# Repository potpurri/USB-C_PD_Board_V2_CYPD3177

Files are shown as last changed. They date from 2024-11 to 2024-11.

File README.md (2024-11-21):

# USB Type-C PD Voltage and Current Selection PCB

This PCB is designed to provide selectable output voltages and currents using the Infineon CYPD3177 USB Type-C port controller. It's equipped with switches that allow you to set the output voltage to 5V, 9V, 12V, 15V, or 20V and the current to 1A, 2A, 3A, 4A, or 5A.

## Features

- **USB Type-C Controller**: CYPD3177 with integrated fault protection and wide operating temperature range.
- **Selectable Output Voltage**: 5V, 9V, 12V, 15V, or 20V.
- **Selectable Output Current**: 1A, 2A, 3A, 4A, or 5A.
- **Compact Design**: Suitable for a variety of applications, including power tools, wearables, IoT devices, and more.
- **Turn ON Switch**: Switch to turn ON/OFF module.

## Voltage and Current Settings

The output voltage and current can be adjusted using switches on the PCB. SW1 is a SP4T switch and SW2 is a SPST switch. To use SW1, SW2 must be in position 1.  Refer to the table below for the settings:

| Voltage Setting | Output Voltage |
|---|---|
| SW1-1 | 5V |
| SW1-2 | 9V |
| SW1-3 | 12V |
| SW1-4 | 15V |
| SW2-2 | 20V |

| Current Setting | Output Current |
|---|---|
| SW1-1 | 1A |
| SW1-2 | 2A |
| SW1-3 | 3A |
| SW1-4 | 4A |
| SW2-2 | 5A |

## Images

### Schematic
Schematic

### 3D Renderings
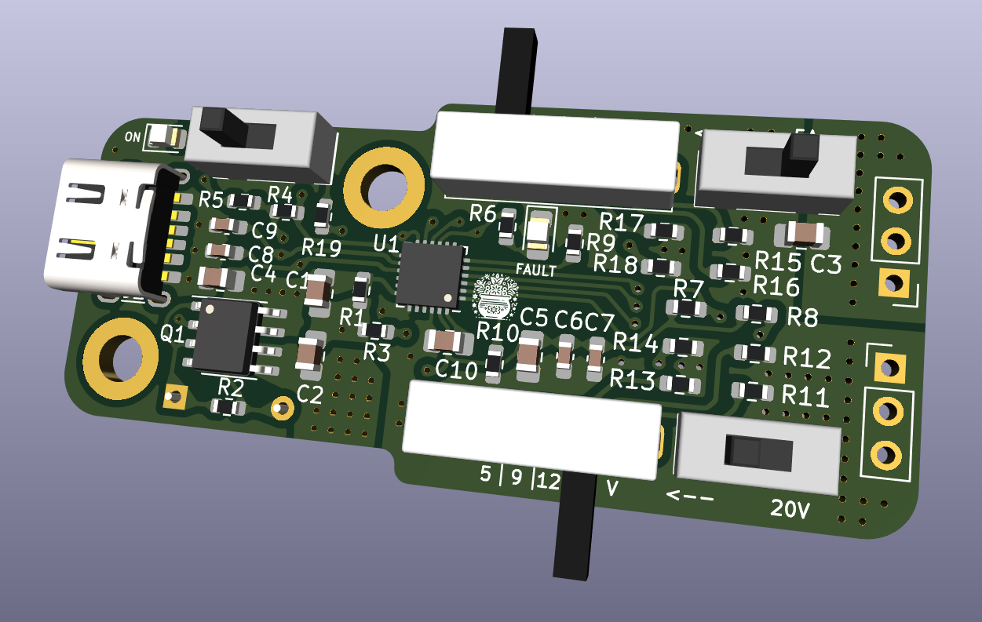
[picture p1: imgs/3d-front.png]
3D Front
- Front View: 
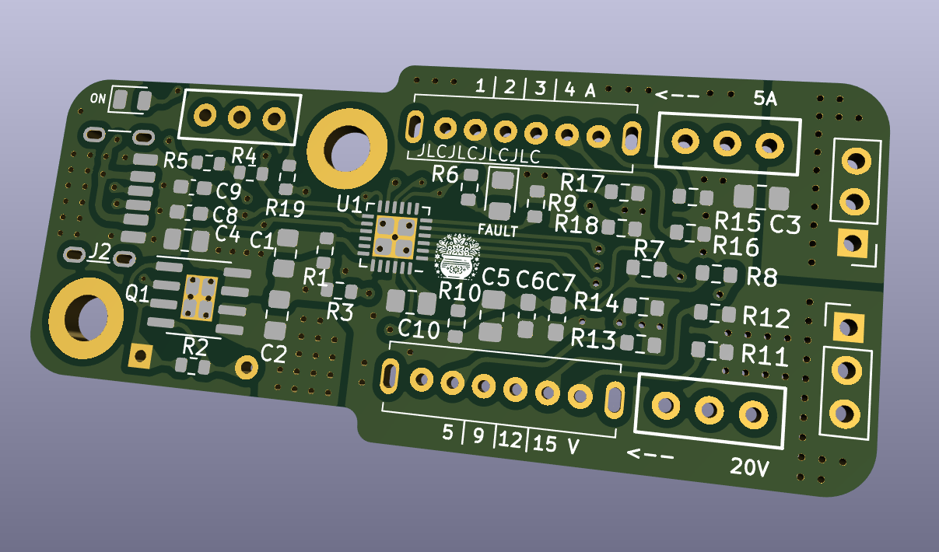
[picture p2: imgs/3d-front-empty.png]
3D Front, no components
- Front View without components: 
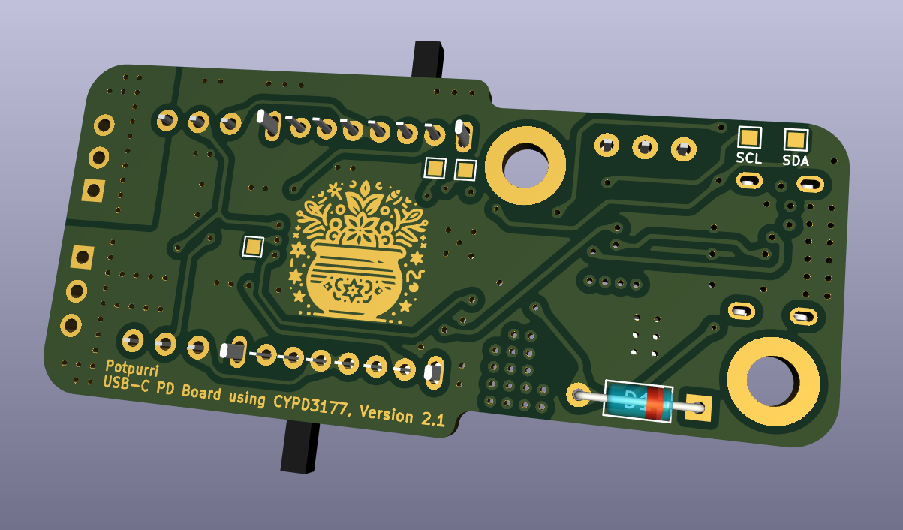
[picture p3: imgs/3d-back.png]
3D Back
- Back View: 

### PCB
**4-Layer Stackup**: Signal Layer, GND Layer, Power Layer, Signal Layer
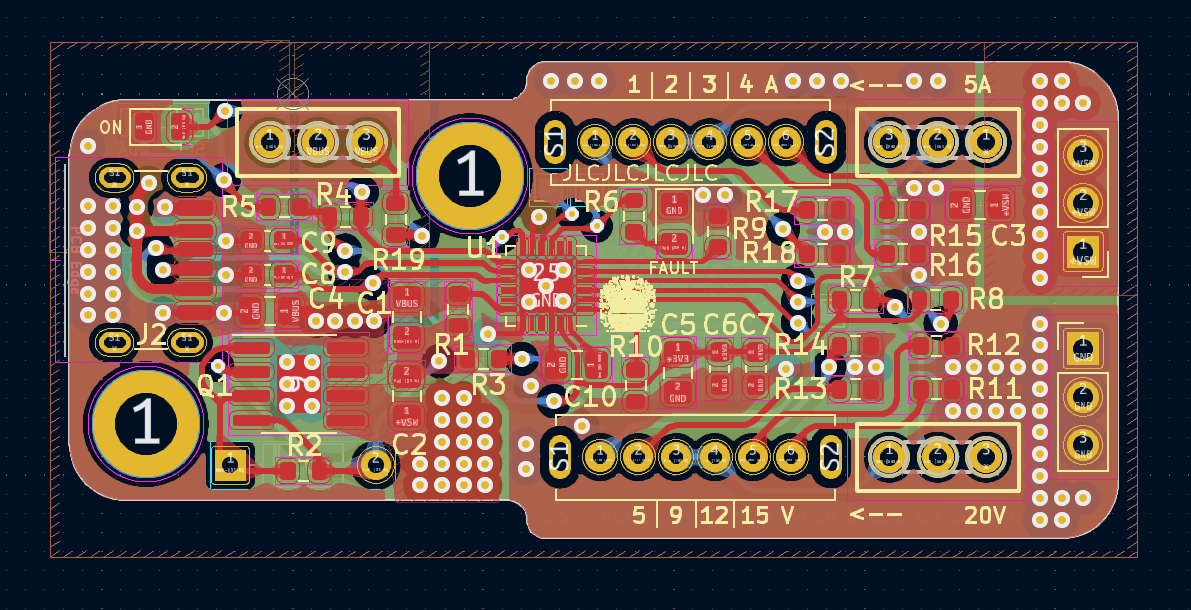
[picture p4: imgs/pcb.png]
PCB - All Layers
- All layers: 
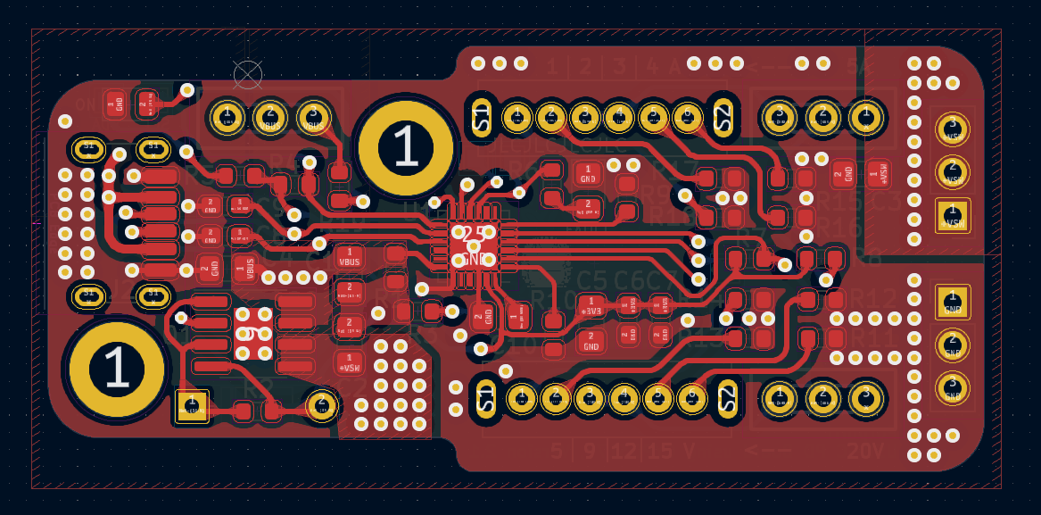
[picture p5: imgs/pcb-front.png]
PCB - Front
- Front traces: 
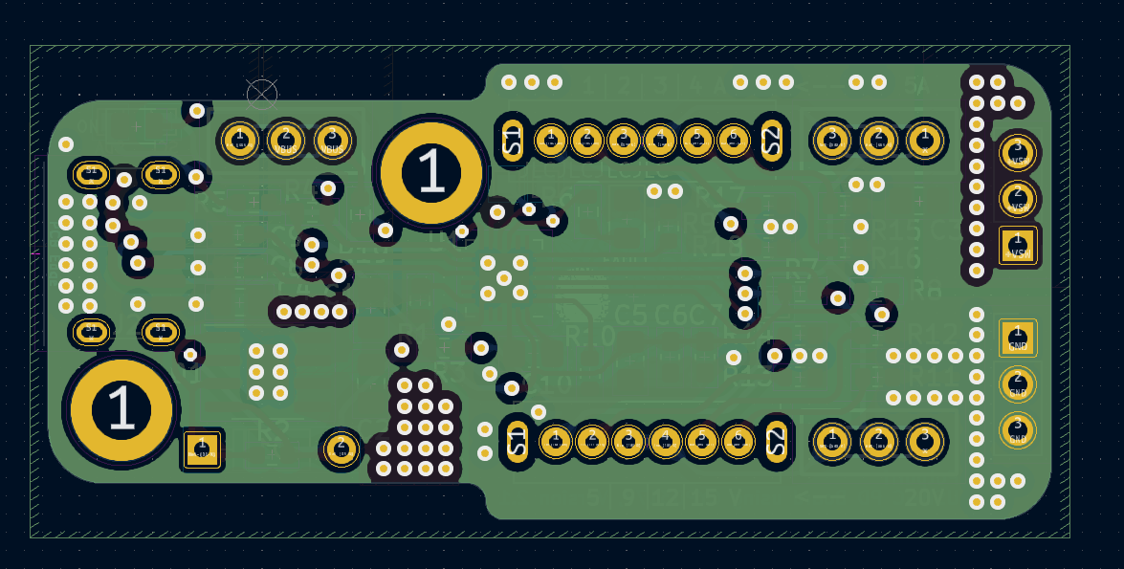
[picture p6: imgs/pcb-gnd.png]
PCB - GND
- GND plane: 
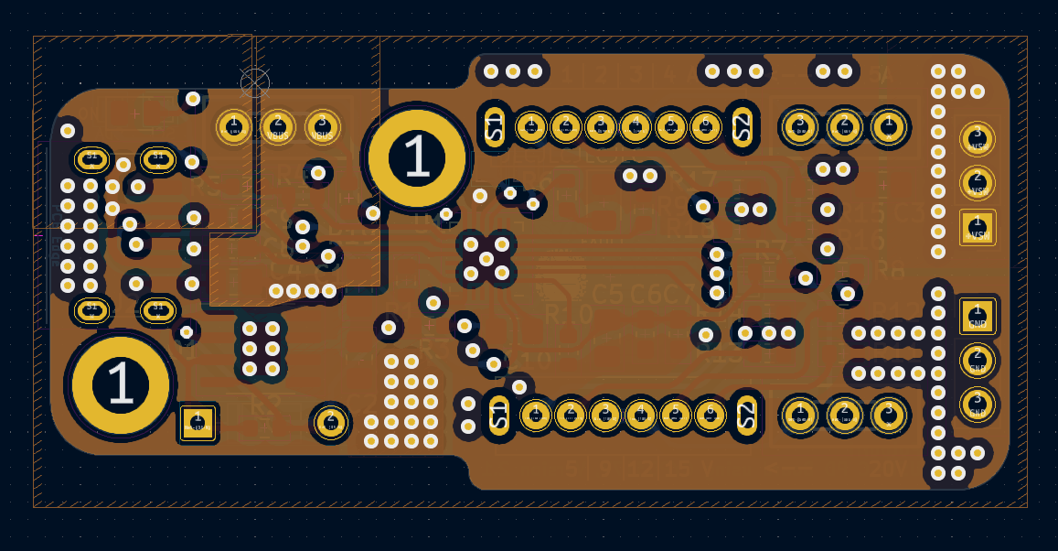
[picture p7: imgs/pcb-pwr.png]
PCB - PWR
- PWR plane: 
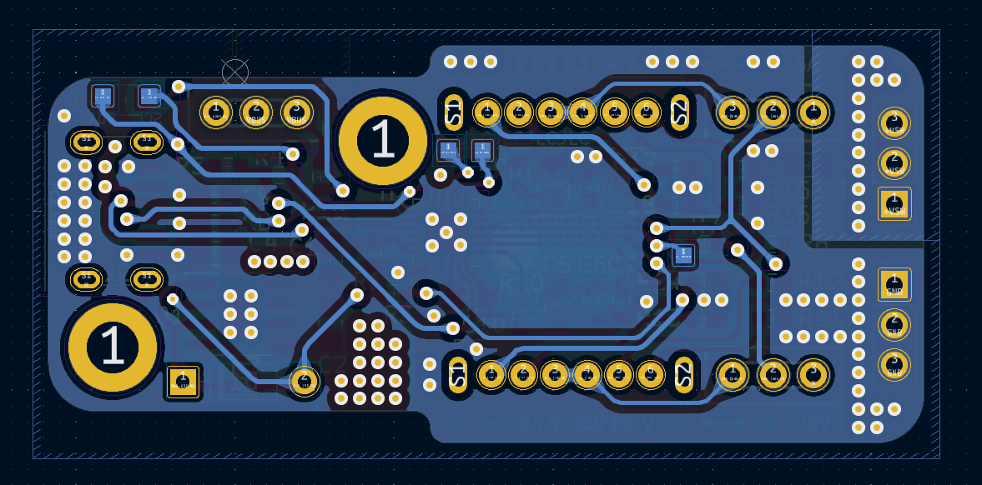
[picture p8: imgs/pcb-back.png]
PCB - Back
- Back traces: 

## Usage

1. **Output Voltage Selection**: Set the desired output voltage by configuring the appropriate switch on the PCB.
2. **Current Selection**: Set the desired current by adjusting the appropriate switch according to the table above.
3. **Connect Device**: Connect the device to the USB Type-C port.
4. **Power Input**: Provide power via the USB Type-C input, and the circuit will manage safe power delivery and maintain output stability.

---

This PCB is ideal for applications needing flexible power delivery with selectable voltage and current options.

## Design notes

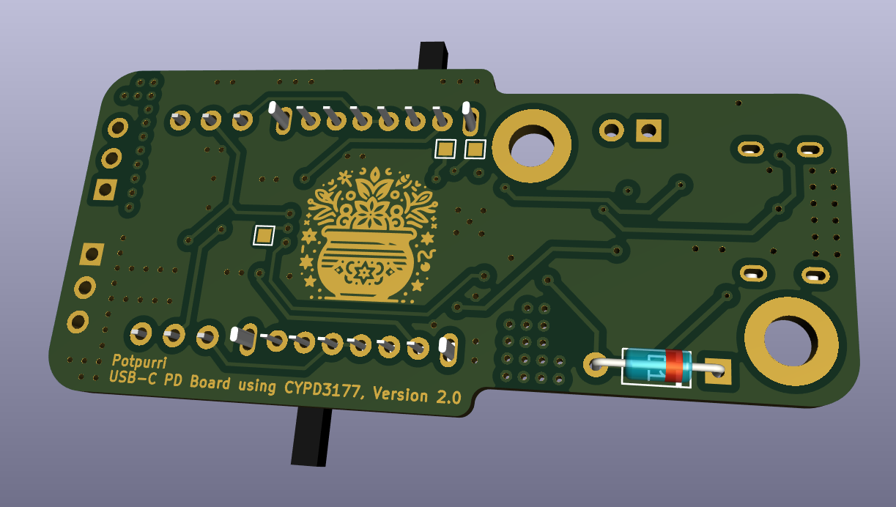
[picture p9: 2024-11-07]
imgs/v2.0/3d-back.png

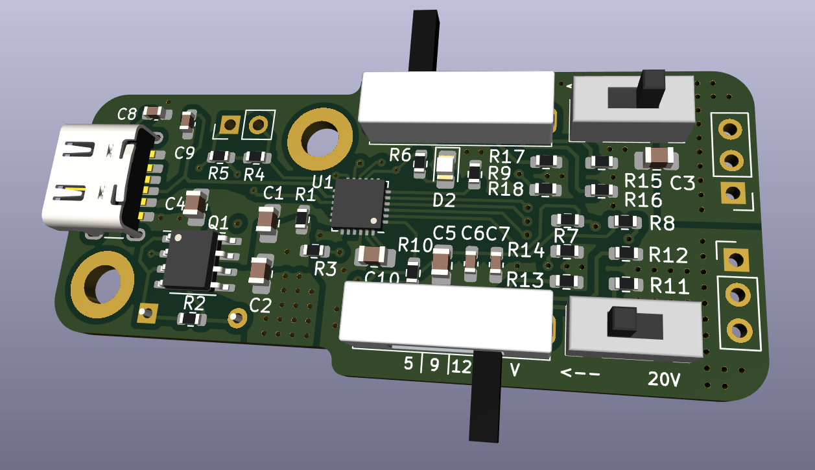
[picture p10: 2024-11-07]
imgs/v2.0/3d-front.png

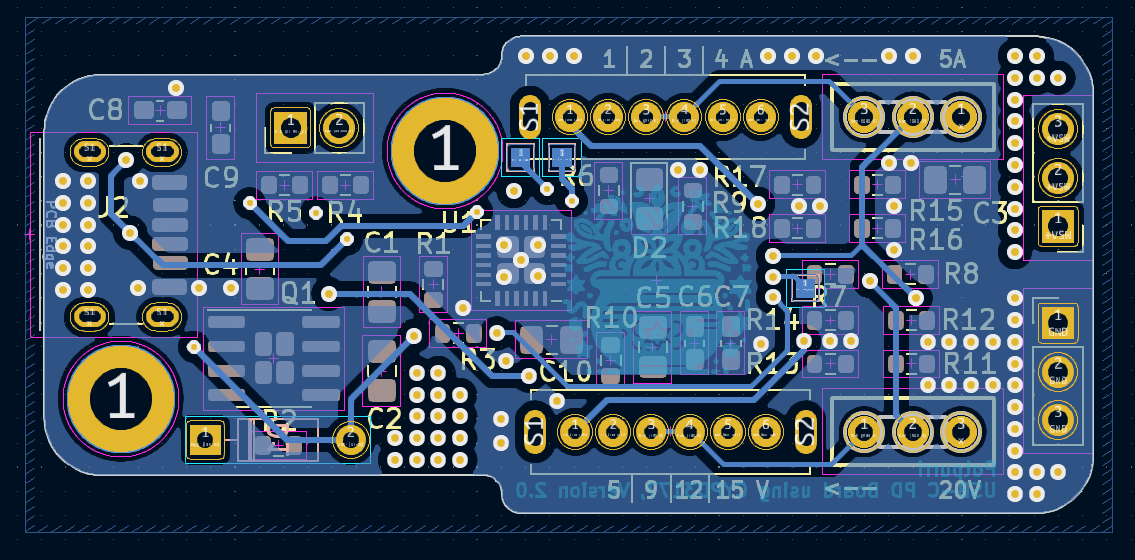
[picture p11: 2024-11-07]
imgs/v2.0/pcb-back.png

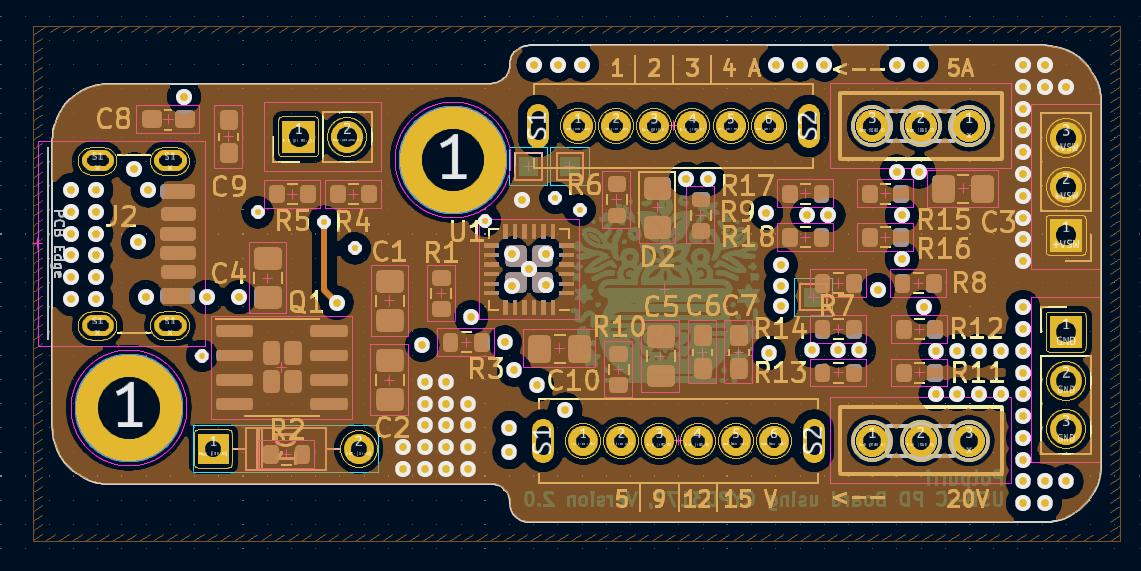
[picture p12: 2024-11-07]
imgs/v2.0/pcb-pwr.png

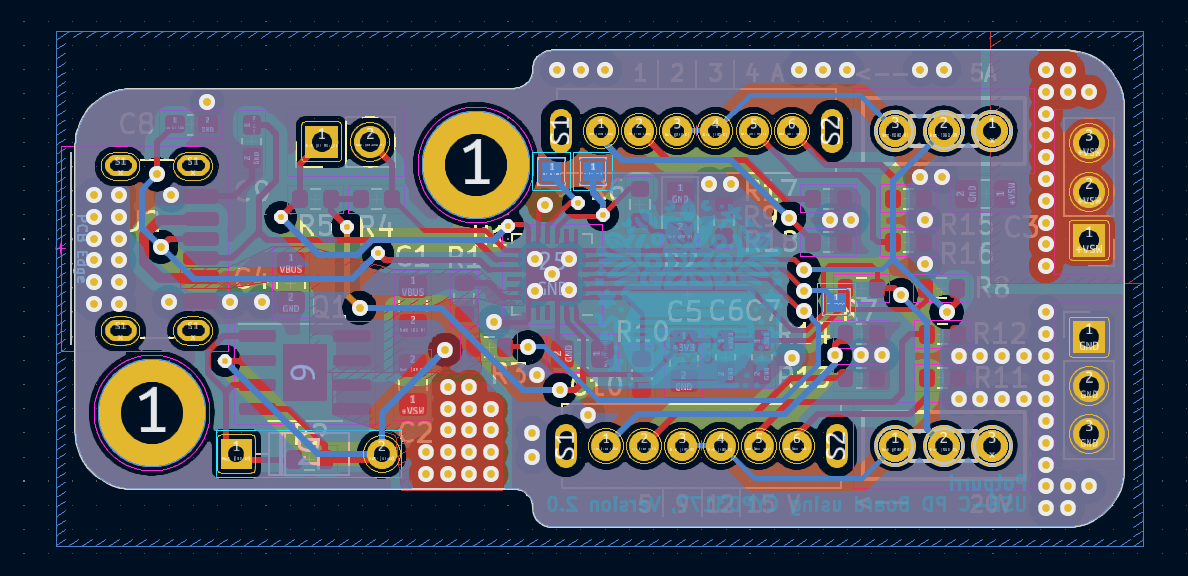
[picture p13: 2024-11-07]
imgs/v2.0/pcb.png

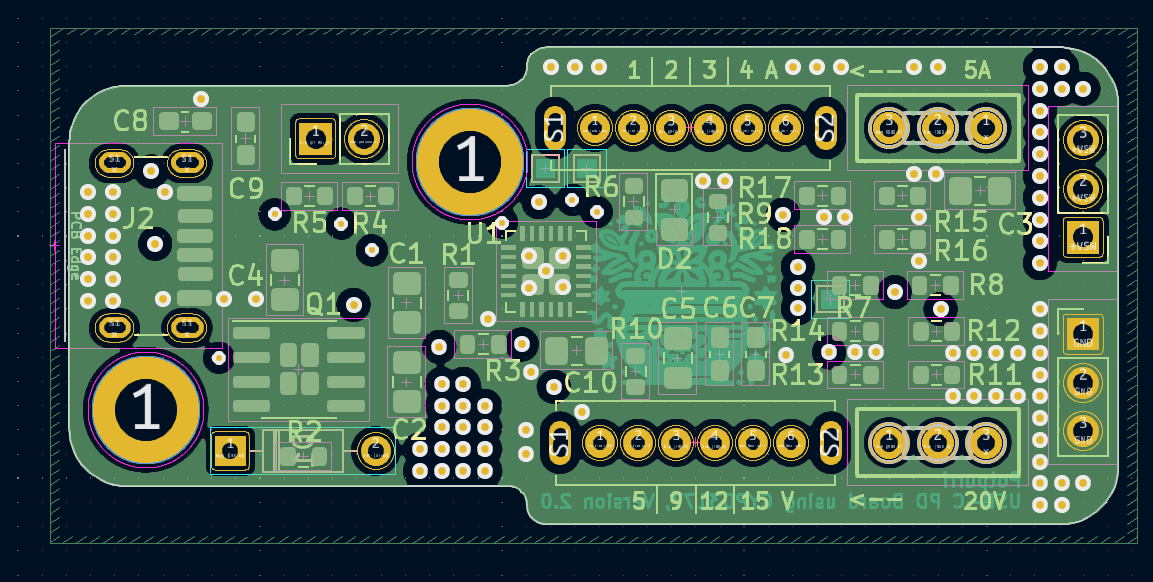
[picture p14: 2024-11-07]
imgs/v2.0/pcb-gnd.png

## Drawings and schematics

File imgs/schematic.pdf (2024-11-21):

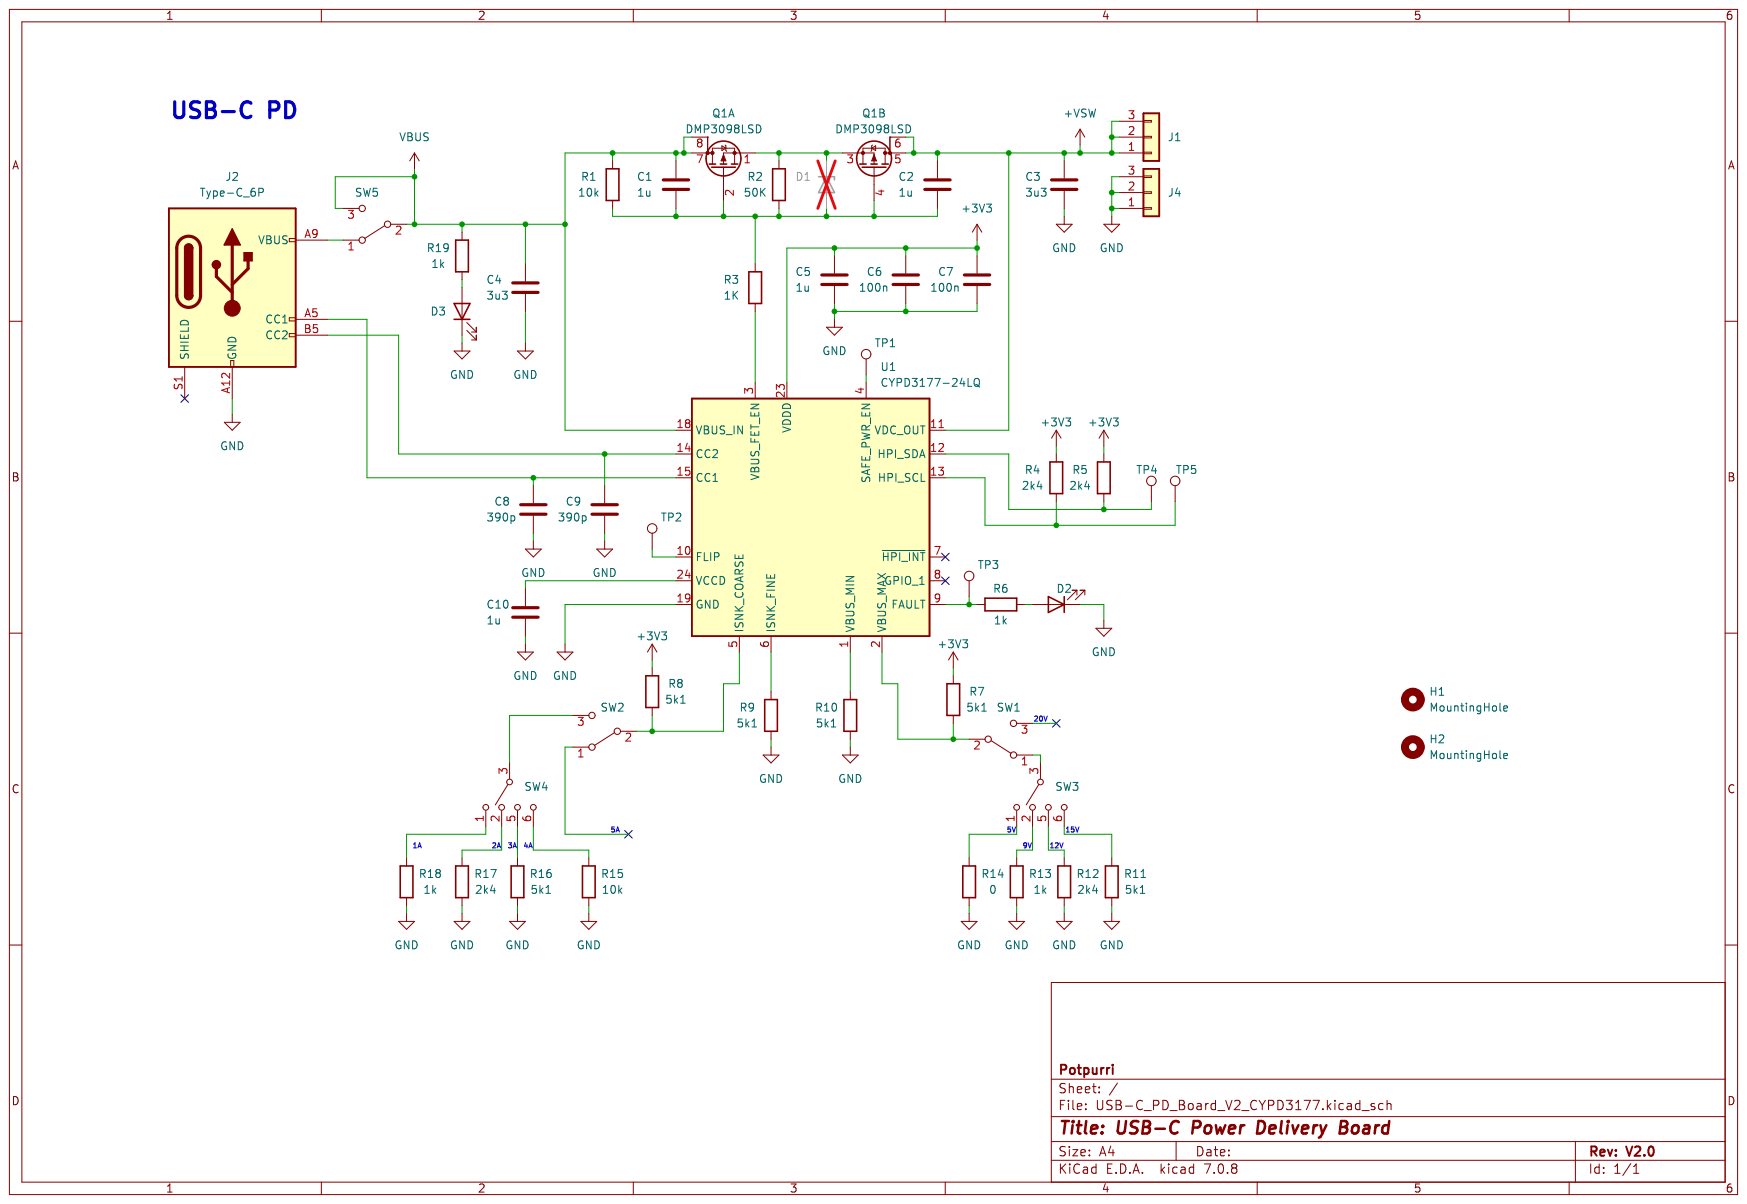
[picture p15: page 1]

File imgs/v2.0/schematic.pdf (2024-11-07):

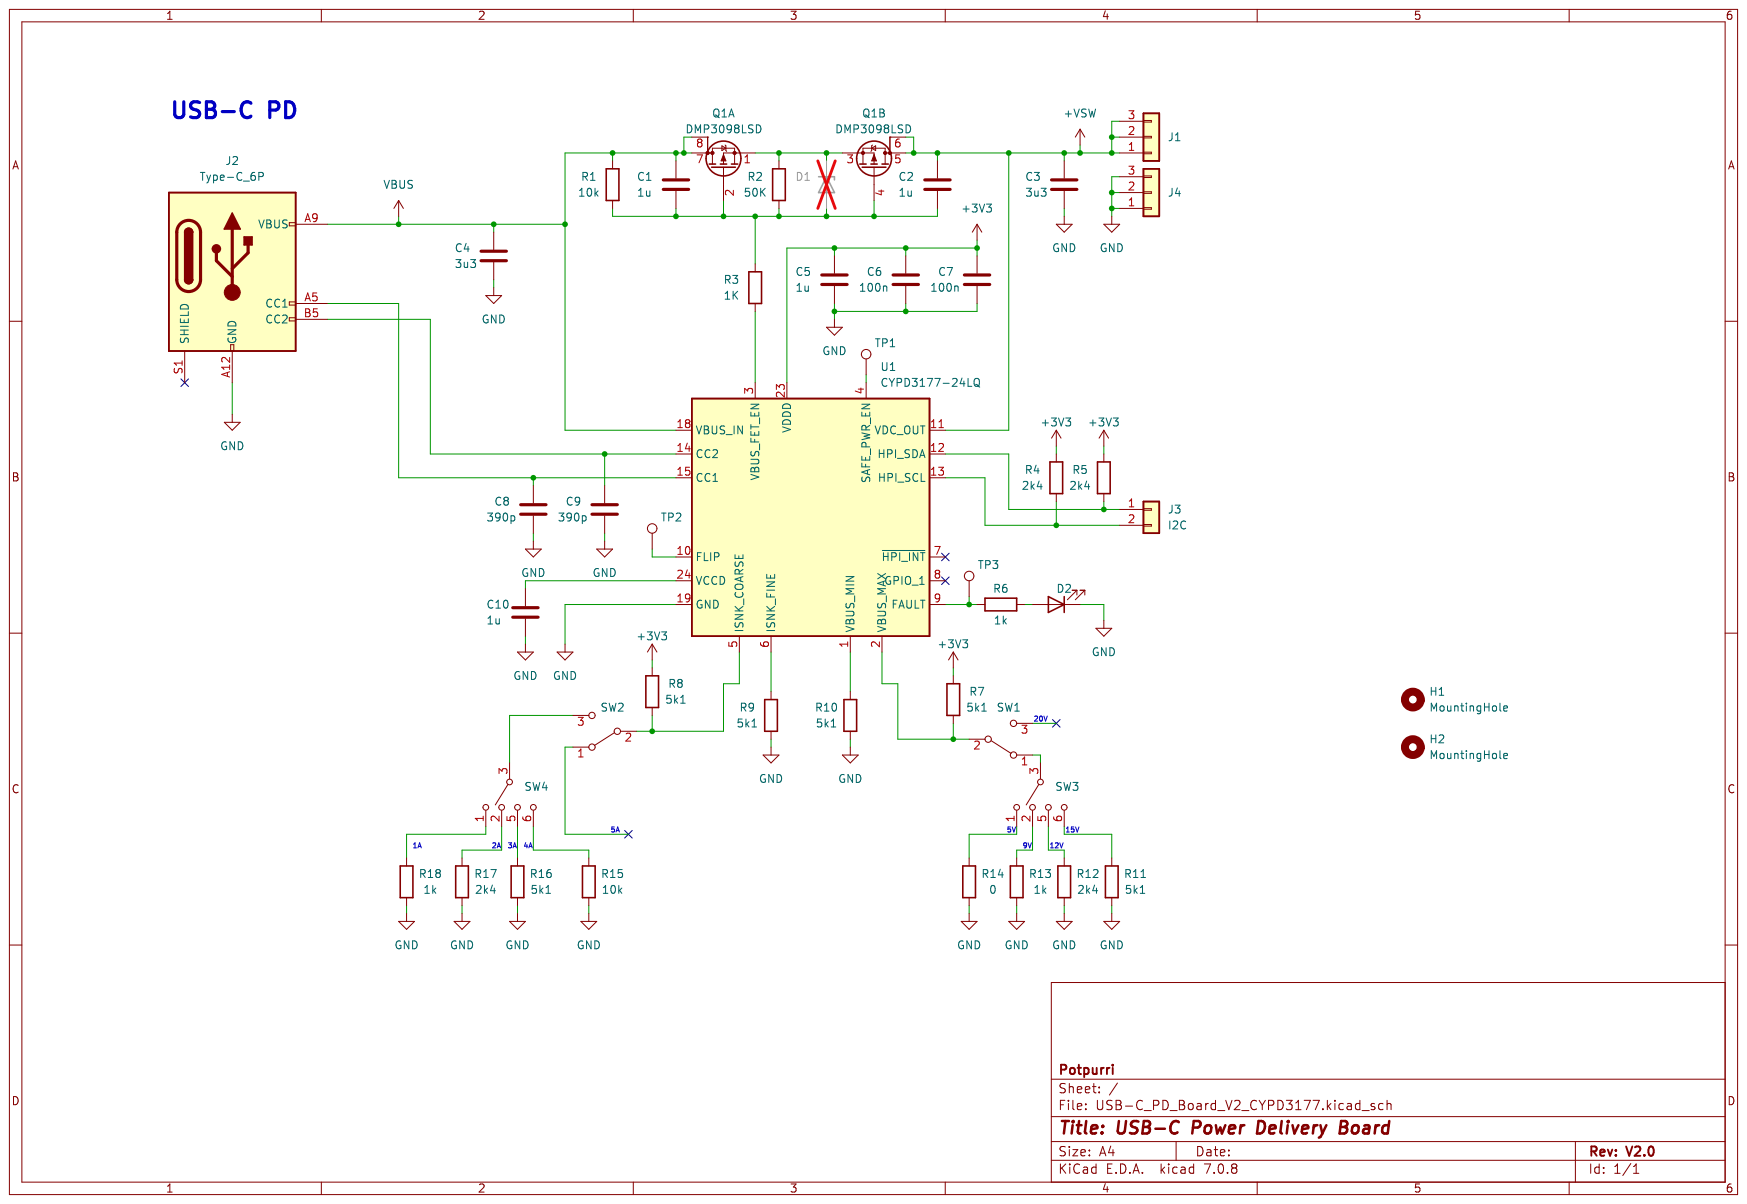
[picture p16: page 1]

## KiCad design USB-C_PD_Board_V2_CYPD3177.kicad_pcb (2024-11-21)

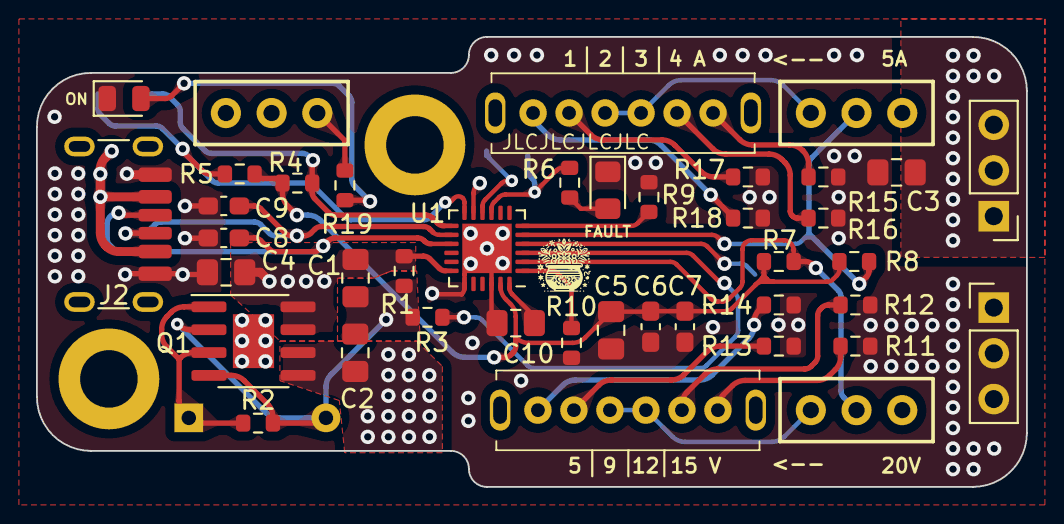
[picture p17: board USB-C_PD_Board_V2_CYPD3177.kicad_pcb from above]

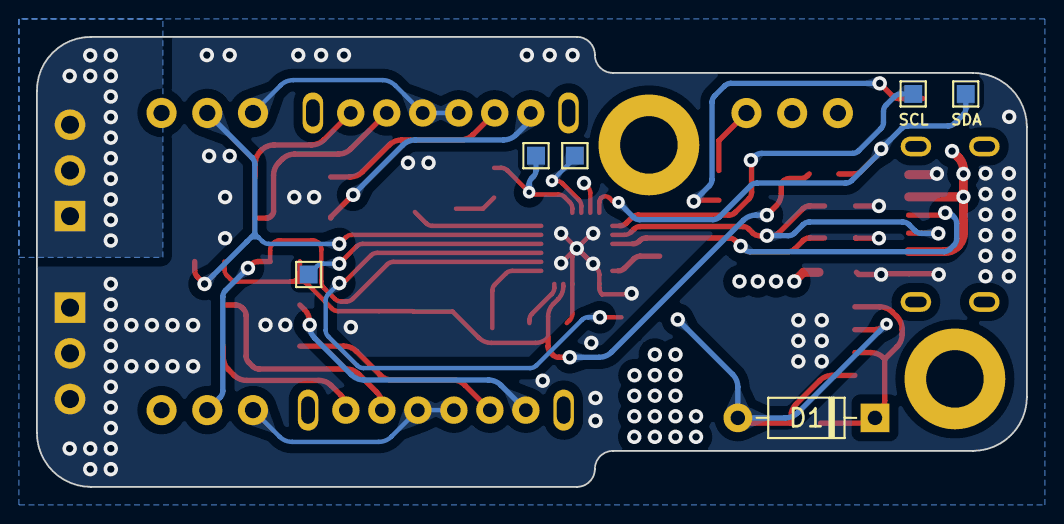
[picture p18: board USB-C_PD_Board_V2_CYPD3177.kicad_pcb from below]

Board: 4 copper layers, 55.0 x 25.0 mm, 49 parts (6 on the bottom side), 32 nets.

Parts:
C1, C2, C5, C10: 1u; C_0805_2012Metric_Pad1.18x1.45mm_HandSolder
C3, C4: 3u3; C_0805_2012Metric_Pad1.18x1.45mm_HandSolder
C6, C7: 100n; C_0603_1608Metric_Pad1.08x0.95mm_HandSolder
C8, C9: 390p; C_0603_1608Metric_Pad1.08x0.95mm_HandSolder
D1: D_Zener; D_DO-35_SOD27_P7.62mm_Horizontal
D2: LED; LED_0805_2012Metric_Pad1.15x1.40mm_HandSolder
D3: LED; LED_0805_2012Metric
H1, H2: MountingHole; MountingHole_3.2mm_M3_DIN965_Pad
J1, J4: Conn_01x03; PinHeader_1x03_P2.54mm_Vertical
J2: Type-C_6P; USB-C 6 Pin - Long pads
Q1: DMP3098LSD; SOIC-8-1EP_3.9x4.9mm_P1.27mm_EP2.29x3mm
R1, R15: 10k; R_0603_1608Metric
R2: 50K; R_0603_1608Metric
R3: 1K; R_0603_1608Metric
R4, R5, R12, R17: 2k4; R_0603_1608Metric
R6, R13, R18, R19: 1k; R_0603_1608Metric
R7, R8, R9, R10, R11, R16: 5k1; R_0603_1608Metric
R14: 0; R_0603_1608Metric
SW1, SW2, SW5: SW_SPDT; Schiebeschalter SS-12D00
SW3, SW4: SK-14D01-G 6
TP1, TP2, TP3, TP4, TP5: TestPoint; TestPoint_Pad_1.0x1.0mm
U1: CYPD3177-24LQ; QFN-24-1EP_4x4mm_P0.5mm_EP2.75x2.75mm

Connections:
+3V3: C5.1, C6.1, C7.1, R4.1, R5.1, R7.1, R8.1, U1.23 (VDDD)
+VSW: C2.1, C3.1, J1.1, J1.2, J1.3, Q1.5 (D), Q1.6 (G), U1.11 (VDC_OUT)
GND: C3.2, C4.2, C5.2, C6.2, C7.2, C8.2, C9.2, C10.2, D2.1 (K), D3.1 (K), J2.A12 (GND), J2.B12 (GND), J4.1, J4.2, J4.3, R9.2, R10.2, R11.2, R12.2, R13.2, R14.2, R15.2, R16.2, R17.2, R18.2, U1.19 (GND), U1.22 (GND), U1.25 (GND)
unnamed: C1.2, C2.2, D1.2 (A), Q1.2 (G), Q1.4 (G), R1.2, R2.2, R3.1
unnamed: D1.1 (K), Q1.1 (S), Q1.3 (S), R2.1
unnamed: D2.2 (A), R6.1
unnamed: D3.2 (A), R19.1
unnamed: C8.1, J2.A5 (CC1), U1.15 (CC1)
unnamed: C9.1, J2.B5 (CC2), U1.14 (CC2)
unnamed: R11.1, SW3.6
unnamed: R12.1, SW3.5
unnamed: R13.1, SW3.2
unnamed: R14.1, SW3.1
unnamed: R15.1, SW4.6
unnamed: R16.1, SW4.5
unnamed: R17.1, SW4.2
unnamed: R18.1, SW4.1
unnamed: SW1.1 (A), SW3.3, SW3.4
unnamed: R7.2, SW1.2 (B), U1.2 (VBUS_MAX)
unnamed: R8.2, SW2.2 (B), U1.5 (ISNK_COARSE)
unnamed: SW2.3 (C), SW4.3, SW4.4
unnamed: J2.A9 (VBUS), J2.B9 (VBUS), SW5.1 (A)
unnamed: R6.2, TP3.1, U1.9 (FAULT)
unnamed: TP2.1, U1.10 (FLIP)
unnamed: R4.2, TP5.1, U1.13 (HPI_SCL)
unnamed: R5.2, TP4.1, U1.12 (HPI_SDA)
unnamed: R9.1, U1.6 (ISNK_FINE)
unnamed: TP1.1, U1.4 (SAFE_PWR_EN)
unnamed: R3.2, U1.3 (VBUS_FET_EN)
unnamed: R10.1, U1.1 (VBUS_MIN)
unnamed: C10.1, U1.24 (VCCD)
VBUS: C1.1, C4.1, Q1.7 (D), Q1.8 (G), R1.1, R19.2, SW5.2 (B), SW5.3 (C), U1.18 (VBUS_IN)

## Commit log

2024-11-05 layout started
    [USB-C_PD_Board_V2_CYPD3177.kicad_pcb, USB-C_PD_Board_V2_CYPD3177.kicad_sch]
2024-11-06 started routing
    [USB-C_PD_Board_V2_CYPD3177.kicad_pcb, USB-C_PD_Board_V2_CYPD3177.kicad_sch]
2024-11-07 pcb layout and routing done!
    [USB-C_PD_Board_V2_CYPD3177.kicad_pcb]
2024-11-07 Donegit add .
    [USB-C_PD_Board_V2_CYPD3177.kicad_pcb]
2024-11-07 Added jlc serial number silk screen
    [USB-C_PD_Board_V2_CYPD3177.kicad_pcb]
2024-11-21 added turn on/off switch, added diode to indicate on state
    [USB-C_PD_Board_V2_CYPD3177.kicad_pcb, USB-C_PD_Board_V2_CYPD3177.kicad_sch]
2024-11-21 added tear drops and curved traces
    [USB-C_PD_Board_V2_CYPD3177.kicad_pcb]
2024-12-16 added gerbers
    [USB-C_PD_Board_V2_CYPD3177-B_Cu.gbr, USB-C_PD_Board_V2_CYPD3177-B_Mask.gbr, USB-C_PD_Board_V2_CYPD3177-B_Paste.gbr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]
